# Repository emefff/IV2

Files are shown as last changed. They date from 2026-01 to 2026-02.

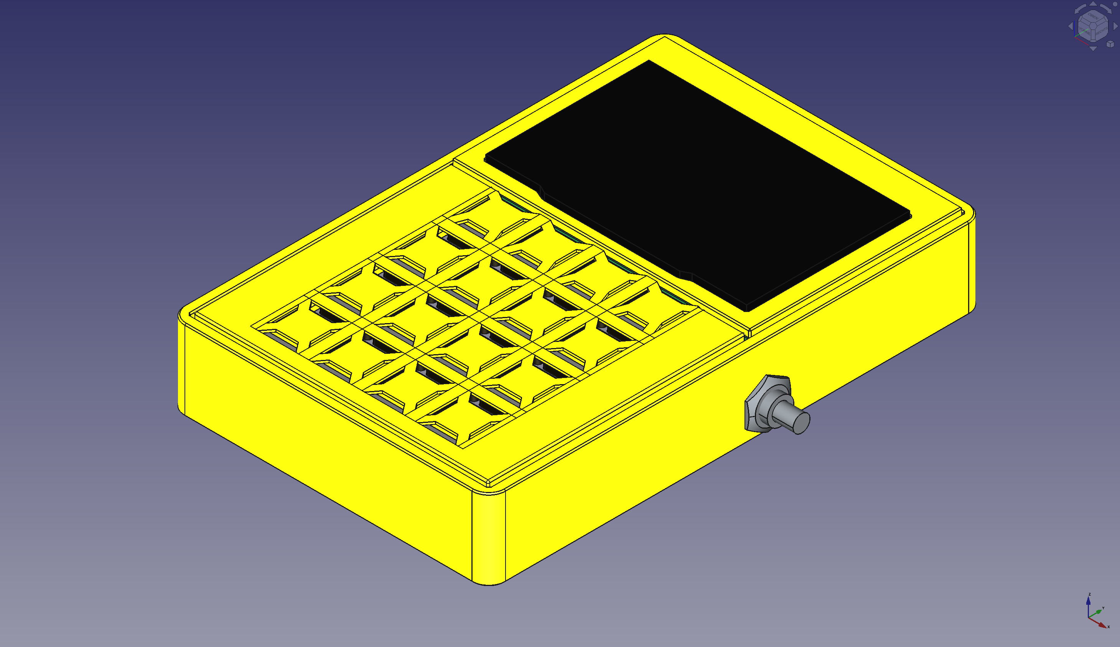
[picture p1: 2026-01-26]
hardware/CAD_overview.png

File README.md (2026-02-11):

# IVEE2 - a Powerful Programmable RPN Calculator based on IVEE

Version 1.0, (c) 2026 by emefff based on the code by deetee/zooxo.
This software is covered by the 3-clause BSD license.

## Purpose
IVEE2 is a port of IVEE to nice!nanov2. It includes some changes that make use of the faster MCU, more RAM and flash space. The main driver behind this was the limited space left on the original IVEE on ProMicro. As far as I remember only one single byte was free on the original calculator. The original code of IVEE can be found in

https://github.com/zooxo/iv

Much of it still present in IVEE2, I am publishing this with kind permission of the original developer, whom I hereby want to thank for his great work. I built his calculator many years ago, mostly by hand without any usage of CAD apart from the housing, which turned out to be rather big and clumsy. Being a fan of RPN calculators and especially the HP lineup, it gives me great pleasure to having bit this bullet and come up with this and being able to present a codebase, that has, in my opinion, great possiblities for the future on this chip. 
Nice!nanov2 is probably best known in the DIY keyboard builder community, where it is used for programmable keyboards and the like. It also has BLE capbility and uses very low power, has an onboard LiIon charging controller and USB-C connectivity. Thus, I can even imagine OTA capability for flashing and in operation for this device. Apart from that, I think of it as a worthy replacement for ESP32 in a lot of scenarios, especially for devices on battery power. 
Being an amateur programming and software enthusiast I used Kilo Code with mostly Codex-5.1, MiniMax-M2.1 and Claude Sonnet 4.5 for developing IVEE2. From this rather overwhelming experience I must say, I do not see a bright future for programmers. The evolution of the codebase was rapid, it took me about 2.5 weeks in Dec. 2025 with just 2-3 hours per day (more on weekends though). The debugging features are, from the viewpoint of an amateur C++ programmer, vastly superior than I imagined. On the other hand, being an amateur, I probably do not see where code has turned out laborious and perhaps inefficient. My approach to this was rather practical and user driven. Two of the used coding agents where very analytical in their approach to developing new functions or debugging. In the end, the codebase includes a great amount of diagnostic code, readily available for anyone to dive in. 

## Recommendations

From my experience, I started this project with Arduino, PlatformIO is the much better IDE in conjunction with  nice!nanov2. With Arduino I was not even able to upload anything, some knock-off boards do not even allow uploading .uf2 binaries, although they claim being able. Thus I recommend anyone building his/her own IVEE2 to use:

-) PlatformIO as IDE, my platformio.ini is included.

-) the original Nice!NanoV2. Granted, it is not cheap, but some of the knock-offs clearly do not work. 

-) also solder a reset button to the board. Sometimes it needs two resets before uploading the firmware.

-) a very common LiIon battery like the one used here, which can be found anywhere on this planet. If your battery capacity is even higher, nice!nanov2 allows to solder a resistor to change the charging current to 500mA instead of the standard 100mA 
(fine by me, increases battery life but takes longer to charge)

## Changes in IVEE2

### Overview of changes

-) enhanced floating point precision, doubles are now double precision instead of single.

-) 4 line stack display. I prefer this over the 2 line display of the original.

-) 32kB user memory for more storage in program mode and also longer programs. 

-) Gauss Kronrod integration instead of Simpson rule: Changing to this method allows for solving very difficult integrals
   numerically. The accuracy of this method can be adapted via GK_MAX_DEPTH. Currently it is set for acceptable duration.
   The implemented integration algorithm beats HP-42S, HP-15C and HP-41C (with ADVANCED or PPC module integration routines) 
   any time in both speed and accuracy.
   
-) WP34s style solver: the solver of WP34s written in assembler was ported. It is very capable and switches between different
   methods combining bisection, secant, quadratic interpolation, and Ridder's method. The original code can be found here:
   https://sourceforge.net/projects/wp34s/files/ .
   
-) 100 registers in flash ranging from 0-99, storing and recalling via usual commands STO and RCL.

-) 100 registers in RAM ranging from 0-99: storing and recalling via two new commands STR and RCR.

-) 1x1 pixel graphs for more accurate graphs in FPLOT.

-) 5 digit floating point display.

-) wear leveling of flash storage. nice!nanov2 can only delete 4kB pages. In order to be usable for years, a rotating wear-leveling is 
   applied to the whole user storage.
   
-) the new TOP (moveprgtop() in code) command moves a program to top of list in PRG mode: In order to not have to repeatedly UP 
   a program to the top of the list in PRG mode, mainly to FPLOT a function, the PRG chosen directly moves to the top of the list. 
   Sorting is done in RAM, only a single rewrite or user flash is necessary. TOP is on the 9 key (= KEY4 in code) in PRG mode.
   
-) Annunciator (_, f, g) moved to top right corner.

-) Builtin functions use RAM registers instead of flash.

-) CLK function slightly changed, enter hours, minutes, seconds consecutively on stack:
   e.g. 11 ENTER, 22 ENTER, 45 CLK
   starts the clock at 11:22:45. The clock does not use the built-in RTC of the nice!nanov2 but is drift compensated.
   
### More registers

In IVEE2, more registers are usable in flash and in RAM. Both range from 0-99 now. I mainly use RAM regs for intermediate storage of variables in functions, that have to be read and written very quickly. For the flash registers use the usual commands STO and RCL. For the new RAM registers use STR and RCR in a similar fashion. 

### Plotting functions

The new chip has vastly more RAM, so the full screen buffer for SSD1306 is not an issue. 1x1 pixel graphs look a lot finer that the previous 2x2 pixels. A comparison between IVEE and IVEE2 with ln from 0 to 2 is shown in the following image. The new printing algorithm also connects the dots with line elements:

<p align="center">
  
</p>

Notice also the size difference, IVEE has been built without CAD (only later the box was modeled 'around' what was already built). IVEE2 was modelled 95% in CAD --> nearly 40% of volume saved.

Just like with IVEE, the function to plot must be placed on top in the program list (use TOP for this in PRG mode). Just enter the limits and plot the function with "0 ENTER 2 FPLOT". 

### Integration algorithm 
Being an RPN calculator enthusiast and aware of their historic significance in science and engineering, I really wanted to include a better algorithm in IVEE2. An algorithm that can even outperform the algorithms present on some of the 'stars' in the RPN sky. There are many examples of functions that cannot be solved adequately with some of the most cherished (and expensive) RPN calculators. To readers of the HP Journal, specifically issue 8/1980, where professor William Kahan presented the capabilties and shortcomings of the integration algorithm developed for HP-34C, which is, to my knowledge, also included in HP-15C, HP-41C (Advantage Module) and HP-42s, this is not news. Personally, I tested numerous calculators and integration algorithms in user programs of the above mentioned calculators if they are able to solve the following integral numerically, among others. It can be found in HP Journal 8/1980 p. 28 (https://hparchive.com/Journals/HPJ-1980-08.pdf):

$$
\int_{-128}^{128} [u(u^2-47^2)(u^2-88^2)(u^2-117^2)]^2  du = 1.31026895247E28
$$

On first glance, this is solvable analytically, probably by a 16 year old pupil, right? But numerically, this integral is a different story. It is spiky between the roots and reaching large arguments. Any algorithm tackling this must either be able to resolve the spikes with a great number of intervals or be adaptive. To prove this integral is far from trivial numerically, the following image shows results calculated by the famous RPN calculators HP-41CX, HP-15C and HP-42S:

<p align="center">
  
</p>

HP41c uses the INTEG command from the Advantage module, the others use their onboard integration algorithm. All three calculators fail solving the integral. They are able to solve it in the halved interval from 0 to 128, though. This is also mentioned by Prof. Kahan in above article:

<p align="center">
  
</p>

The only way out with these calculators in solving such integrals is to write your own integration algorithms in user code, die-hard HP41c users might even write MCODE. 
In IVEE2, the above function can make use of RAM register nr. 1 (of course it can be done with the stack too) when entering something like the following. The squares of 47, 88 and 117 are stored in flash registers 97, 98 and 99:

"1, STR, CLR, 1, RCR, 2, POW, 99, RCL, -, 1, RCR, 2, POW, 98, RCL, -, *, 1, RCR, 2, POW, 97, RCL, -, *, 1, RCR, *, 2, POW"

To integrate this function place in on top of the PRG list and enter the limits on the stack: "128 N ENTER ENTER N FINT". 

Let's see how IVEE2 does:
<p align="center">
  
</p>

Clearly, we find the implemented algorithm can in fact solve this integral. The only downside is the number of digits displayed. Internally, looking at the serial monitor, we will find a vastly better accuracy. On stack level a we find the absolute error of the calculation, stack level b shows the result. 

### Solver/Root finder

The solver implemented is, more or less, an exact port from wp34s (written in Assembler, the source can be found here: https://sourceforge.net/projects/wp34s/files/) to C++. It is a very capable solver, combining and switching between bisection, secant, quadratic interpolation, and Ridder's method. Like with integration (FINT), the function of interesest must be placed on top of the PRG list. To find the root of a function enter a start interval (X and Y) and press FSOLVE. There are measures in place, that start the solver anyway with random values, if only one or no value is on the stack. However, in a function with multiple roots you will likely not find the desired root (or none at all!) if no interval is given. For example, with above function we get:

"40 ENTER 80 FSOLVE" --> "7.17527E-13"

"50 FSOLVE" --> "47"

"90 FSOLVE" --> "88"

"118 FSOLVE" --> "117"

Clearly, the better you already know your function, the more likely you will find all roots. 

## Programming

Programming is basically unchanged from IVEE but with a lot more storage in flash, so I will just give a brief description. If you are familiar with programming the HP-41C or HP42S, then you will not have any difficulties. Programs are entered RPN style, like on HP-41C, but we can also use the menu like on HP-42s (similar but a bit different. We can choose functions from the DICT or USER menu). The main difference to the RPN style on HP-41c is that we don't need RTN or VIEW to present a value on the stack, we also don't have the function LBL within the function itself. The name of the function is outside the function/program. Already included complex number capabilites for every function are an improvement over HP-41C, but displaying is not as convenient as on HP-42s (HP-42s: single line complex numbers, but reduced number of digits, IVEE2: two line display of complex numbers). For example, the program "0, SWP, CPX, EXP" returns EXP(i*x). And indeed, "PI F(X)" gives "a -1, i -8.74228E-8", the complex identity 

$$
\exp(i*\pi) = -1
$$

with a bit of a rounding error in the imaginary part, though. 

Now, let us test a version of the TVM formula with monthly payments (we use the notation on the HP-12c):

$$
FV(n) = PV * (1+i)^n + PMT * [(1+i)^n − 1)/i]
$$

i...yearly interest rate

n...months

FV...future value

PMT...monthly payment

PV...present value

Entering this on IVEE2 we have different options. Making use of flash and RAM registers we may enter a formula in PRG mode like this:

"0, STR, CLR, 0, RCL, 1, +, 0, RCR, POW, 1, RCL, *, 0, RCL, 1, +, 0, RCR, POW, 1, -, 0, RCL, /, 2, RCL, *, +, 3, RCL, -"

First we store n in RAM reg nr. 0, we CLR the stack, then enter the formula. When we put it on top in PRG mode, we can use FSOLV (fS internally) to solve for n at FV = 0, that is, we want to find the number of months we have to pay back the 100 bucks. For our example we use the follwing numbers in 4 flash registers 0-3:

i = 0.08 ("0.08 ENTER 0 STO")

PV = 1000 ("1000 ENTER 1 STO")

PMT = -100 ("100 N ENTER 2 STO")

FV = 0 ("0 ENTER 3 STO")

Just pressing FSOLV will yield: 20.921237. Comparing with HP-12c (i=8, PV=1000, PMT=-100, FV=0) pressing the n-button:

<p align="center">
  
</p>

The results match as HP-12c rounds up to the next integer. From this funny little example we have learned that an interest rate of 8% is quite high and we have to pay more than double the amount back. Horrible!

## Hardware

Of couse, a one-off model like this calculator is destined for 3D printing. In the shared folder 'hardware' you'll find a FreeCAD file with the latest design. Everything is modeled in CAD. This can be quite deceiving: thinking you have modeled 'everything', you forget about stupid mistakes to be made with stuff you didn't model. This happened here with the wiring. Any sane person would not model this in 3D, the designing of every wire alone would take too long, with limited benefit. But here it would have helped: the distance between MCU board and battery is crucial for the position of the USB-C cutout in the housing! Forgetting about this or not leaving enough room for wires that bend and need space, has left me with a MCU board position, that did not quite fit the modeled USB-cutout. A very basic and stupid mistake. :-(

Overview of the CAD:
<p align="center">
  
</p>

View of the parts inside:

<p align="center">
  
</p>

The 3D printed parts are all PETG except the display frame which was made in PLA. The parts are:

-) housing

-) display frame

-) MCU board adapter (includes a tiny socket for a reset button)

-) keyboard matrix (a thin matrix covering the buttons and leaving a flat surface for a thin printed keyboard overlay)

The layout of the calculator is based around a perforated circuit board with standoffs to the bottom for making the necessary space for wiring, battery and MCU board. The MCU board is mounted onto an adapter which is in turn mounted to the circuit board. Everything is made to last and to be replaceable. The keys are quite generic, as is the SSD1306 display. The whole assembly is held in the housing with 6 magnets glued into the housing. The battery is glued in place, as is the display. Screw heads are covered with the display frame and the keyboard matrix, respectively. The inner workings of my build look like this:

<p align="center">
  
</p>

Try to keep it nice and tidy, a long battery cable pays off in the end and during the build. 
The keyboard matrix shown in these pictures is still the old version. 

Recommendations for 3D printing:
If you can, use at least PETG on a TXT sheet (not as brittle as PLA, a PLA housing can break when falling off a table). Print a 5mm brim or mouse ears at the corners of the housing as it is quite large. Also use a brim on the keyboard matrix, the adapter is quite small, maybe a smaller brim will do also. The display frame in PLA does not need a brim, it sticks very well to a PEI sheet. Use structural mode and 3 perimeters for the housing and two perimeters for the keyboard matrix (both see some mechanical loads), maybe even 0.15mm layers. The keyboard matrix must stay somewhat flexible for a lower button force. There are even variants of the housing in the FreeCAD file that include a brim in CAD. Feel free to use this or add a brim in your slicer. 

### Additional Parts needed

-) Cables

-) wires

-) 6x standoff nuts for short M3 * 5mm screws

-) 6x 4 * 4 *2mm magnets

-) 6x M3 * 5mm screws

-) 1x perforated PCB, prefer the ones with lugged holes, not the ones with just holes. The lugs make soldering something to the holes easier

-) double-sided tape, also to correct height differences

-) hot glue

-) Kapton tape for isolation where needed

-) 2x resistor for the voltage divider, here 2x 10k (not good regarding voltage resulotion but ok)

-) 1x On/Off switch

-) USB-C cable for flashing and charging the LiIon battery

-) 1x 4 * 4mm reset button, fits the twerp on the adapter for the MU

-) optional phone charger 

# ToDos

-) new keyboard overlay to be designed fitting this keyboard layout. The layout shown in the images is still the old design. I will upload the files when this is completed.

-) anything important that comes up, we'll see.

maybes:

-) perhaps move the annunciator back to the old position for base modes other than scientific.

-) the statistical functions were not tested, because I do not need them. With the increased flash registers there are much more possibilities.

-) perhaps use the onboard RTC for the clock and maybe implement a stopwatch, date and time functions. Maybe similar to TIME module on HP41c. 

Have fun,

emefff@gmx.at

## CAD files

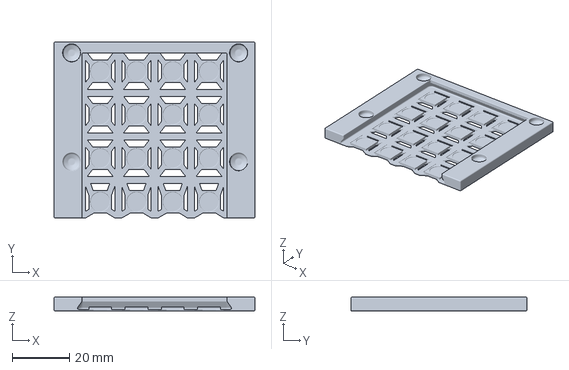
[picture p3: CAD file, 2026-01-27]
hardware/IVEE2_Model_V7-Keyboardmatrix.3mf
70.3 x 61.5 x 4.80 mm

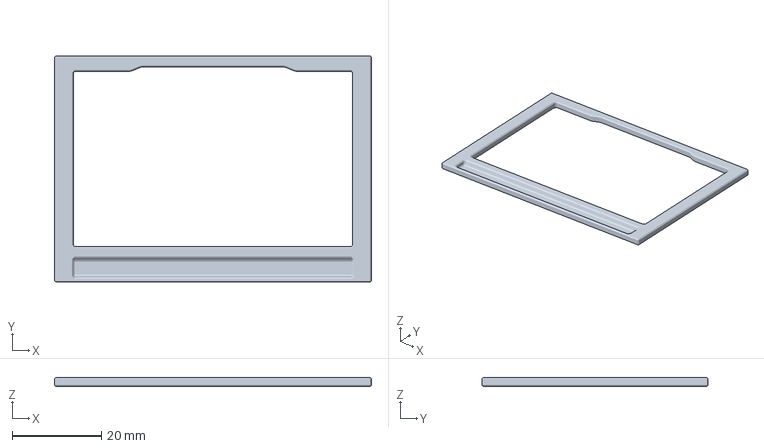
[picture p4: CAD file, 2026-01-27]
hardware/IVEE2_Model_V5-frame_display.3mf
71.1 x 50.8 x 2.00 mm

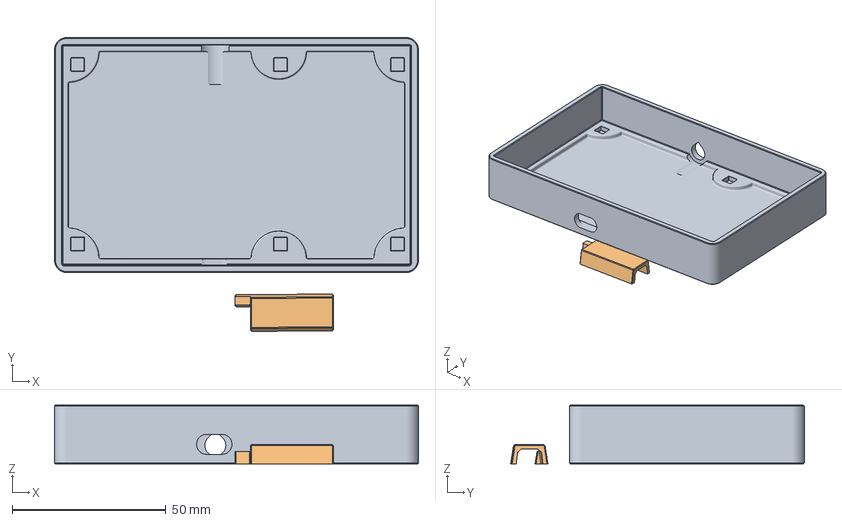
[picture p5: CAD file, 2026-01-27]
hardware/IVEE2_Model_V4-Box_wCutouts_higher+0.5.3mf
118.5 x 95.7 x 19.2 mm
IVEE_V2_Model_V4_Gehaeuse_hoeher-BOX_wCutouts_sideWalls_higher+0
IVEE_V2_Model_V4_Gehaeuse_hoeher-ADAPTER_new_eumelLonger+1mm

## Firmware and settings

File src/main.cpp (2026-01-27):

/*

  ____________________

  Welcome to IVEE2 - A Powerful Programmable and Expandable RPN Calculator based on IVEE
  Version 1.0, (c) 2026 by emefff based on the code by deetee/zooxo. 
  This software is covered by the 3-clause BSD license.
  See also: https://github.com/emefff/ivee2 
  ____________________


IVEE2 is a port of IVEE to nice!nanoV2. All credit for the orginal design goes to detee, his code for Arduino 
ProMicro is the basis for this calculator. You can find the original code in

https://github.com/zooxo/iv

With his kind permission, I can publish the ported code. Basic functions of the calculator are 
the same, with some enhancements of built-in code and the benefits that come with a more capable chip. 

The main purpose of this port is to have a simple calculator like IVEE and at the same time have a calculator
that still can evolve. This was not possible on ProMicro because there was only a single byte left in flash. 
I strongly encourage everyone to add functions (both in code and FORTH) and to learn about
how a calculator works. Maybe there's also an educational purpose/value in this for EE or SE students.

Kilo Code was used in developing this calculator, models used were mostly Codex-5.1, MiniMax M2.1 and Claude Sonnet 4.5.
The calculator features a lot of diagnostics over serial and was quite extensively tested. The main development took 
about 2.5 weeks in Dec. 2025 with 2-3 hours per day, more on weekends. The author is not a professional programmer or software
engineer, rather an advanced amateur software and calculator enthusiast. 

Changes and enhancements include:

-) enhanced floating point precision, doubles are now double precision instead of single.
-) 4 line stack display. I prefer this over the 2 line display of the original.
-) 32kB user memory for more storage in program mode and also longer programs. 
-) Gauss Kronrod integration instead of Simpson rule: Changing to this method allows for solving very difficult integrals
   numerically. The accuracy of this method can be adapted via GK_MAX_DEPTH. Currently it is set for acceptable duration.
   The implemented integration algorithm beats HP42, HP15C and HP41c (with ADVANCED or PPC module integration routines) 
   any time in both speed and accuracy.
-) WP34s style solver: the solver of WP34s written in assembler was ported. It is very capable and switches between different
   methods combining bisection, secant, quadratic interpolation, and Ridder's method. The original code can be found here:
   https://sourceforge.net/projects/wp34s/files/ .
-) 100 registers in flash ranging from 0-99, storing and recalling via usual commands STO and RCL.
-) 100 registers in RAM ranging from 0-99: storing and recalling via two new commands STR and RCR.
-) 1x1 pixel graphs for more accurate graphs in FPLOT.
-) 5 digit floating point display.
-) wear leveling of flash storage. nice!nanov2 can only delete 4kB pages. In order to be usable for years, a rotating wear-leveling is 
   applied to the whole user storage.
-) the new TOP (moveprgtop() in code) command moves a program to top of list in PRG mode: In order to not have to repeatedly UP 
   a program to the top of the list in PRG mode, mainly to FPLOT a function, the PRG chosen directly moves to the top of the list. 
   Sorting is done in RAM, only a single rewrite or user flash is necessary. TOP is on the 9 key (= KEY4 in code) in PRG mode.
-) Annunciator (_, f, g) moved to top right corner.
-) Builtin functions use RAM registers instead of flash.
-) CLK function slightly changed, enter hours, minutes, seconds consecutively on stack:
   e.g. 11 ENTER, 22 ENTER, 45 CLK
   starts the clock at 11:22:45. The clock does not use the built-in RTC of the nice!nanov2 but is drift compensated

   
This concludes the most important changes exposed to the user.

The following part of this docstring is mostly copied from https://github.com/zooxo/iv and adapted to IVEE2 to explain the basic original
and the new functions:

Ivee2 is operated by 16 keys only it offers a wide range of functions
  and possibilities:
  - 122 intrinsic functions based on FORTH
  - increased user space (32kB)
  - Programming: Handle up to 40 user definable programs with max. 256 steps
                 (Edit, New, Rename, Move, Delete, Send, Load)
  - Dictionary of all commands (sorted), words and programs
  - Fast user definable menu (longpressed F-key)
  - Calculations with complex numbers for nearly every function
  - Calculus (f(x), plot, solve, integrate)
  - Basic math operations in number systems with selectable BASE
  - Business calculator mode (accuracy of 18 digits)
  - Save up to 100 numbers/constants permanently
  - Save up to 100 numbers in RAM
  - Statistics and line best fit (not tested yet)
  - Many unit conversions
  - Clock and Torch function
  - Basic system functions (Battery voltage, Brightness (does not work with my SSD1306, though), Screensaver)
  - due to massive RAM and flash compared to ProMicro, IVEE2 is expandable in many ways.


  ____________________

   KEYBOARD, SHORTCUTS
  ____________________

    F(G)[OFF]{MENU}  7(S+)[SCLR]    8(PRG)[BASE]    9(/)[MOD]
    E(SWAP)[ROT]     4(DICT)[USR]   5(FX)[FPLOT]    6(*)[LIT]
    N(OVER)[PICK]    1(RCL)[STO]    2(SOLVE)[FINT]  3(-)[LIT-]
    X(CLR)[TOFF]     0(CPLX)[BATT]  .(R<>P)[CLK]    #(+)[LIT+]

    PRG Shortcuts:                  BASE/HEX Shortcuts:
                    9 TOP            
             5 OUT  6 UP              4 E  5 F
      1 NEW  2 IN   3 DOWN            1 B  2 C    3 D
      0 REN  . DEL  D EDIT            0 A  . A~F

    MENU/DICT/REN Navigation:       SUM/STAT/L.R. Storage Registers:
             Q1  Q2  Q3  Q4           7 SN  8 SX   9 SY
      UP     E   4   5   6                  5 SXX  6 SXY
      DOWN   N   1   2   3
             PREV0   .NEXT


  ____________________

   DISPLAY, INDICATORS
  ____________________

    >        ... Empty stack, ready to calculate
    >        ... Indicates selected program in program selection mode
    <        ... Indicates selected program step in program editing mode
    a~z      ... Stack level
    _        ... Indicates number input
    i, angle ... Imaginary part, imaginary angle
    B        ... BASE mode indicator
    n BASE   ... Numeric base of BASE mode
    !        ... Indicates float of data stack (data loss in lowest stack level)
    ^, v     ... F-key, G-key
                
                
  ____________________

   LIMITS
  ____________________

    26   ... Maximum data stack size (a...z)
    7    ... Maximum number of displayed significant digits of a number
    99   ... Maximum number of decimal exponent digits (1E-99 < X < 1E99)
    12   ... Maximum size of text display (see EMIT, CTX)
    100  ... Maximum amount of (complex) numbers saved permanently (0...99)
    100  ... Maximum amount of (complex) numbers saved in RAM      (0...99)
    3    ... Maximum number of characters for naming an user program
    40   ... Maximum number of user programs
    256  ... Maximum size of an user program (steps)
    ~32000  ... Maximum size (steps) of all user programs
    64   ... Maximum size of address stack ("deep of nesting")
    32   ... Maximal definable command slots of user menu                
                

  ____________________

   BROWSING MENUS
  ____________________

    To navigate through the menu of some functions (MENU, DICT, USR, renamePRG)
    all selectable items are divided into four sections. Every section has its
    own up and down key (section I: E/N, section II: 4/1, section III: 5/2 and
    section IV: 6/3).
    To move to the previous or next entry (regardless which section is selected)
    the keys "0" or "." can be used. To select one of the four presented items
    use the appropriate function key (F/7/8/9) or escape the menu with "X".


  ____________________

   PROGRAMMING
  ____________________

    Ivee2 is able to deal with up to 40 user programs with a total number of
    ~32000 steps/commands. To handle/edit/create user programs enter the program selector mode
    with PRG.
    While in the program selection mode on the left side of the display the
    available programs are numbered and listed. On the right side of the display
    the number of programs, the memory used and the memory available are shown.
    To navigate between programs use the cursor keys E (up) and N (down).
    Edit a selected program with # or press 1 to enter a new program.
    To delete a program press "." - to rename it use the key 0.
    You can move a program with 6 up or with 3 down. A program can be moved to the 
    top of the list with TOP pressing 9. Note that the top program
    has special calculus features (f(x), plot, solve, integrate).
    To send a program (does not include the program name) via USB to another
    computer press "5". Note that corresponding ascii characters will be sent
    (see chapter DICTIONARY, second column). In a similar way programs can be
    send from another computer to Ivee (press key 2) and will be stored as new
    program.
    With the 3 powerful commands @, ! and EXE (see chapter DICTIONARY) it is
    even possible to manipulate the program memory and execute code.
    A program is structured into the three parts NAME, COMMANDS and EOP-marker.
    Please note that the length of the program name is restricted to 3
    characters and the maximum number of program steps is restricted to 256.
    
    
  ____________________

   BASE, BUSINESS MODE
  ____________________

    To calculate with integer values in other numeric base enter the base and
    select the BASE command (ie 16 BASE to calculate with hexadecimal numbers).
    To return to the scientific mode press BASE again. When changing the mode
    the whole stack will be converted (as far as appropriate) to the new base.
    Numbers will be displayed in groups of four digits in two lines with a
    B-indicator (BASE) on the left side and the base itself on the right side of
    the first line. Pressing "E" enters four zeros.
    Note that only basic operations (/*-+) and some stack operations are
    supported. To enter digits bigger than 9 (ie F) press "." followed by a key
    (ie 5 to enter F).
    The BASE can be stored permanently. However, currently it is set to start in 
    scientific mode, always.
    Entering the BASE mode with 10 activates the business mode to deal with big
    numbers and high accuracy, like trillions of dollars with cent accuracy.
    Numbers are grouped into triples and two digits after the decimal dot
    (cents) are supported.


  ____________________

   CALCULUS
  ____________________

    Ivee2 is able to analyze the first user defined program. Note that you can
    move the desired user program to the first position with the TOP command pressing
    9 directly or using the keys 6 or 3 in program mode (PRG).
    To calculate the value of a function use F(X).
    To find the root of a function enter a start interval (X and Y) and press FSOLVE. 
    There are measures in place that start the solver anyway with random values, if no
    value is on the stack or only one value. However, in a function with multiple roots
    you will likely not find the desired root (or none at all!) if no interval is given.
    Enter the x-range (from Y to X) before plotting a function (FPLOT) or
    calculating an integral (FINT).


  ____________________

   COMMANDS
  ____________________

  MEMORY
       functions         mem[]       EEPROM
    |<--intrinsic-->|<--builtin-->|<--user-->|
     0               76            121        164
              MAXCMDI^      MAXCMDB^   MAXCMDU^


  OVERVIEW
    Intrinsic
      Forth  DUP DROP NEGATE / * - + MOD DICT SWAP ROT PICK
             < = <> > KEY EMIT BASE BEGIN UNTIL IF ELSE THEN @ !
      System 0~9 . E STO RCL CLR USR NAND INTEGER PI INV SIN EXP LN
             COMPLEX REC<>POL F(X) FPLOT FSOLVE FINTEGRATE
             PRG T+ PSE EXE BREAK CLRTEXT ISREAL
             SUM+ SUM- SUMCLR COMB PERM STAT LR
             BATT LIT LIT+ LIT- CLOCK OFF TOFF STR RCR
    Builtin
      Forth  OVER HEX AND NOT OR ABS
      Other  $ SQRT POWER POWER10 LOG LN! PV ND QE HMS>H H>HMS CLOCK
             COS TAN ASIN ACOS ATAN SINH COSH TANH ASINH ACOSH ATANH
             DEG>RAD RAD>DEG C>F F>C KM>MI MI>KM M>FT FT>M CM>IN IN>CM
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
void loop() {
  //Serial.print("MAGIC: "); Serial.println(digitalRead(MAGICKEYPIN));

#if ENABLE_WRITE_COUNTERS
  // Handle diagnostic commands via Serial
  if (Serial.available() > 0) {
    char cmd = Serial.read();
    if (cmd == 'S' || cmd == 's') {
      EEPROM.printWriteStats();
    } else if (cmd == 'R' || cmd == 'r') {
      EEPROM.resetWriteStats();
    } else if (cmd == 'B' || cmd == 'b') {
      // Brightness wear-leveling test
      Serial.println(F("\n[TEST] Running brightness wear-leveling test..."));
      Serial.println(F("[TEST] Writing 20 brightness values"));
      for (int i = 0; i < 20; i++) {
        EEPROM.putBrightness(100 + i);
        Serial.print('.');
        delay(10);
      }
      Serial.println(F("\n[TEST] Complete. Send 'S' to see distribution."));
    } else if (cmd == 'D' || cmd == 'd') {
      // Darktime wear-leveling test
      Serial.println(F("\n[TEST] Running darktime wear-leveling test..."));
      Serial.println(F("[TEST] Writing 12 darktime values"));
      for (int i = 0; i < 12; i++) {
        EEPROM.putDarktime(6 + i);
        Serial.print('.');
        delay(10);
      }
      Serial.println(F("\n[TEST] Complete. Send 'S' to see distribution."));
    }
  }
#endif

  if (isprintscreen) isprintscreen = printscreen(); // Print screen
  if (pause) { // Pause
    delaylong(pause);
    pause = 0;
  }

  if (mp) { // *** Execute/run code
    if (mp < sizeof(mem)) key = mem[mp++]; // Builtin
    else if (mp < sizeof(mem) + sou){
      byte tmp;
      EEPROM.get(mp - sizeof(mem) + EEUSTART, tmp); // read from EEPROM
      key = tmp;                                    // assign to key
      mp++;                                         // post-increment
    }
    else mp = 0; // cmd > MAXCMDU
    
    // log program execution steps
    #if LOG_PRG_MEMPTR
    if (Serial && key != 255) {
      Serial.print("[PRG] mp="); Serial.print(mp);
      Serial.print(" key="); Serial.print(key);
      Serial.print(" dp="); Serial.println(dp);
      Serial.flush(); // Force output
    }
    #endif
    
#if LOG_FX_FI_STACK
    if (Serial && key != _END && key < NOPRINTNOKEY) {
      Serial.print("[EXEC_STEP] cmd="); Serial.print(key);
      if (key < MAXCMDB && key < sizeof(cmd)/sizeof(cmd[0])) {
        Serial.print(" name="); Serial.print(cmd[key]);
      }
      Serial.print(" BEFORE - dp="); Serial.print(dp);
      Serial.print(" ap="); Serial.print(ap);
      Serial.print(" STACK: ");
      for (byte i = 0; i < dp && i < 6; i++) {
        Serial.print(ds[i].r, 3); Serial.print(" ");
      }
      Serial.println();
      Serial.flush();
    }
#endif
    
    if (key >= MAXCMDB && key != _END) apush(mp); // Subroutine detected - branch (only user programs, not builtin RAM commands)
    if (key == _END) { // _END reached
#if LOG_FX_FI_STACK
      if (Serial) {
        Serial.print("[EXEC_END] ap="); Serial.print(ap);
        Serial.print(" dp="); Serial.print(dp);
        Serial.print(" STACK: ");
        for (byte i = 0; i < dp && i < 6; i++) {
          Serial.print(ds[i].r, 3); Serial.print(" ");
        }
        Serial.println();
      }
#endif
      if (ap) mp = apop(); // End of subroutine - return
      else { // End of run
        mp = 0;
        isprintscreen = true; // Finally print screen
        #if LOG_PRG_MEMPTR
          if (Serial) Serial.println("[PRG] Program END - execution complete");
        #endif
      }
    }
    else {
#if LOG_RAM_STORCL
      if (Serial && (key == _STO_RAM || key == _RCL_RAM)) {
        Serial.print("[LOOP] About to execute cmd=");
        Serial.print(key == _STO_RAM ? "STO_RAM" : "RCL_RAM");
        Serial.print(" dp="); Serial.print(dp);
        Serial.print(" isnewnumber="); Serial.println(isnewnumber);
      }
#endif
#if LOG_PRG_MEMPTR
      if (Serial && key == _RCL) {
        Serial.println("[PRG] *** ABOUT TO EXECUTE RCL ***");
      }
#endif
      execute(key);
#if LOG_FX_FI_STACK
      if (Serial && key < NOPRINTNOKEY) {
        Serial.print("[EXEC_STEP] AFTER - dp="); Serial.print(dp);
        Serial.print(" ap="); Serial.print(ap);
        Serial.print(" STACK: ");
        for (byte i = 0; i < dp && i < 6; i++) {
          Serial.print(ds[i].r, 3); Serial.print(" ");
        }
        Serial.println();
        Serial.flush();
      }
#endif
#if LOG_PRG_MEMPTR
      if (Serial && key == _RCL) {
        Serial.println("[PRG] *** RCL EXECUTE DONE ***");
      }
#endif
#if LOG_RAM_STORCL
      if (Serial && (key == _STO_RAM || key == _RCL_RAM)) {
        Serial.print("[LOOP] After execute dp="); Serial.print(dp);
        Serial.print(" isnewnumber="); Serial.println(isnewnumber);
      }
#endif
    }
    digitalWrite(KEYBOARDCOL1, LOW); // Stop by pressing C
    if (!digitalRead(KEYBOARDROW4)) mp = ap = 0;
    digitalWrite(KEYBOARDCOL1, HIGH);
  }

  else { // *** Evaluate valid new key
    if (!(nextFrame())) return; // Idle for next frame
    key = getkey(); // READ KEY
    if (key < NOPRINTNOKEY) { // only if valid key otherwise flooding with NOPRINTNOKEY
      Serial.print("Key read: ");
      Serial.println(key);
      // Debug matrix pins
      Serial.print("COL1: "); Serial.print(digitalRead(KEYBOARDCOL1));
      Serial.print(" ROW4: "); Serial.println(digitalRead(KEYBOARDROW4));
    }

    if (key == KEY13) { // Stop execution
      issolve = isint =  isplot = istorch = false;
      gkResetController();
      clockState.active = false; // Stop clock
      powertimestamp = millis(); // Reset power management timer
    }
    if (key == KEY1 && !base) { // Check MENU (longpressed f)
      if (millis() - timestamp > FLONGPRESSTIME) {
        if (isprgedit) { // Menu from prgedit demanded
          isprgmenu = true; isprgedit = false;
        }
        else { // Menu demanded
          fgm = 0;
          freleased = false;
        }
        ismenu = isprintscreen = true;
        sel = 0; // Comment out, if menu should't start at 0
      }
    }
    else timestamp = millis();

    if (millis() - powertimestamp > darktime * 10000L) { // Dark if no activity
      // Don't sleep if clock is active - keep device running to maintain clock accuracy
      if (!clockState.active) {
        Serial.print("[POWER] Screen timeout after ");
        Serial.print((millis() - powertimestamp) / 1000);
        Serial.print("s (darktime=");
        Serial.print(darktime);
        Serial.print(" = ");
        Serial.print(darktime * 10);
        Serial.println("s)");
        _keygoff();
        isprintscreen = true;
      }
      // Update powertimestamp to prevent repeated checking when clock is active
      powertimestamp = millis();
    }

    if (issolve) { // # SOLVE
      cycles++;

      dp = 0; // Clear stack for new solve

#if LOG_SOLVE
      Serial.print("[SOLVE] before _fnfx mp=");
      Serial.println(mp);
#endif
      bool endpointsReady = evaluateFxImmediate(x0, w0);
      if (endpointsReady) endpointsReady = evaluateFxImmediate(x1, w1);

      if (!endpointsReady) {
        issolve = false;
        msgnr = MSGRUN;
        isprintscreen = true;
      }
      else {
#if LOG_SOLVE
        if (Serial) {
          Serial.print("[SOLVE] y0="); Serial.print(w0);
          Serial.print(" y1="); Serial.println(w1);
        }
#endif

        double root = hybridSolve(x0, x1, w0, w1, 1e-12, 250); //wp34s style solver
        dpushr(root); // Push root found

        if (Serial) { // always serial.print the root.
          Serial.print("\n[SOLVE] Root="); Serial.println(root);
        }
        isnewnumber = true; issolve = false;
        isprintscreen = true;
      }
    }
    else if (isint) { // # INTEGRATE - Adaptive Gauss-Kronrod
      if (!gkController.active) {
        isint = false;
      }
      else {
        cycles++;
#if LOG_FX_FI_STACK
        if (Serial) {
          Serial.print("[FI] BEFORE execute - eval#"); Serial.print(gkEvalCount + 1);
          Serial.print(" node="); Serial.print((int)gkController.nodeIndex);
          Serial.print(" x="); Serial.print(gkCurrentNodePosition(), 8);
          Serial.print(" dp="); Serial.print(dp);
          Serial.print(" ap="); Serial.print(ap);
          Serial.print(" STACK: ");
          for (byte i = 0; i < dp && i < 8; i++) {
            Serial.print("["); Serial.print(i); Serial.print("]=");
            Serial.print(ds[i].r, 6);
            if (ds[i].i != 0.0) {
              Serial.print("+j"); Serial.print(ds[i].i, 6);
            }
            Serial.print(" ");
          }
          Serial.println();
        }
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

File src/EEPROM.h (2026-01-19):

#include <Arduino.h>
#include <stdint.h>
#include <cstring>

//#define FLASH_PAGE_SIZE 0x2000  // 8 KB page, was 4kB 0x1000 before
#define FLASH_PAGE_SIZE 0x8000    // 32 KB page, was 8kB 0x1000 before, notably sluggish with 64kB

#define EEPROM_PAGE_POOL 8                 // Number of rotating 32 KB pages
#define EEPROM_PAGE_HEADER_SIZE 32         // Bytes reserved at top of each page for metadata
static_assert(EEPROM_PAGE_HEADER_SIZE < FLASH_PAGE_SIZE, "EEPROM header must fit inside a page");

constexpr uint32_t kEepromPageMagic = 0x4550524DL; // 'EPRM'
constexpr bool kEnableEepromWrites = true;         // #define DONT_CLEAR_USER_FUNCTIONS on first flashing.

// Wear-leveling diagnostics
#define ENABLE_WRITE_COUNTERS 0  // comment to disable for production
#if ENABLE_WRITE_COUNTERS
#define WRITE_COUNTER_SIZE 256   // Track first 256 logical addresses
static uint32_t writeCounters[WRITE_COUNTER_SIZE] = {0};
#endif

// Wear-leveling for frequently written single-byte values
#define WL_BRIGHTNESS_SLOTS 8    // Rotate brightness across 8 addresses
#define WL_BRIGHTNESS_START 2048 // 256b with MEMNR=10, 2048b with MEMNR=100
#define WL_BRIGHTNESS_INDEX (WL_BRIGHTNESS_START + WL_BRIGHTNESS_SLOTS)
#define WL_DARKTIME_SLOTS 4
#define WL_DARKTIME_START 272
#define WL_DARKTIME_INDEX (WL_DARKTIME_START + WL_DARKTIME_SLOTS)

static inline uint32_t bootloaderStartAddr() {
    constexpr uint32_t BOOTLOADERADDR_REG = 0x10001014UL;
    return *((volatile uint32_t*)BOOTLOADERADDR_REG);
}

static inline uint32_t eepromFlashBase() {
    uint32_t pageSize = NRF_FICR->CODEPAGESIZE;
    uint32_t totalSize = pageSize * NRF_FICR->CODESIZE;
    uint32_t bootAddr = bootloaderStartAddr();
    if (bootAddr == 0xFFFFFFFF) bootAddr = totalSize;
    uint32_t poolSize = FLASH_PAGE_SIZE * EEPROM_PAGE_POOL;
    if (bootAddr < poolSize) bootAddr = poolSize;
    return bootAddr - poolSize; // Lowest address of the rotating pool
}

class EEPROMEmu {
public:
    EEPROMEmu();

#if ENABLE_WRITE_COUNTERS
    void printWriteStats();
    void resetWriteStats();
#endif

    template <typename T>
    void put(int offset, const T& value) {
        ensureInitialized();
        const uint8_t* src = reinterpret_cast<const uint8_t*>(&value);
        size_t len = sizeof(T);
        uint32_t targetAddr = physicalDataAddress(offset);

#if ENABLE_WRITE_COUNTERS
        for (size_t i = 0; i < len && (offset + i) < WRITE_COUNTER_SIZE; ++i) {
            writeCounters[offset + i]++;
        }
#endif

        programBytes(targetAddr, src, len);
    }

    template <typename T>
    void get(int offset, T& value) {
        ensureInitialized();
        const uint8_t* src = reinterpret_cast<const uint8_t*>(physicalDataAddress(offset));
        std::memcpy(&value, src, sizeof(T));
    }

    int length() {
        return FLASH_PAGE_SIZE - EEPROM_PAGE_HEADER_SIZE;
    }

    uint8_t operator[](int address) {
        uint8_t val;
        get(address, val);
        return val;
    }

    void set(int address, uint8_t val) {
        put(address, val);
    }

    bool beginPageRewrite();
    uint32_t activePageBase() const { return pageBase(activePage); }

    // ----- wear-level helpers for small single-byte slots -----
    uint8_t findNextSlot(uint8_t baseAddr, uint8_t numSlots);
    uint8_t findCurrentSlot(uint8_t baseAddr, uint8_t numSlots);
    void putBrightness(uint8_t brightness);
    uint8_t getBrightness();
    void putDarktime(uint8_t darktime);
    uint8_t getDarktime();

private:
    struct PageHeader {
        uint32_t magic;
        uint32_t generation;
        uint32_t generationInverse;
        uint32_t reserved;
    };

    void ensureInitialized();
    void initPool();
    uint32_t poolBase() const { return poolBaseAddr; }
    uint32_t pageBase(uint8_t idx) const { return poolBaseAddr + static_cast<uint32_t>(idx) * FLASH_PAGE_SIZE; }
    uint32_t dataBase(uint8_t idx) const { return pageBase(idx) + EEPROM_PAGE_HEADER_SIZE; }
    uint32_t physicalDataAddress(int offset) const { return dataBase(activePage) + static_cast<uint32_t>(offset); }
    void programBytes(uint32_t targetAddr, const uint8_t* src, size_t len);
    void eraseLogicalPage(uint8_t pageIdx);
    bool readHeader(uint8_t pageIdx, PageHeader& out) const;
    void writeHeader(uint8_t pageIdx, uint32_t generation);
    bool rotateToNextPage();
    uint8_t nextPageIndex(uint8_t idx) const { return (idx + 1) % EEPROM_PAGE_POOL; }

    uint32_t poolBaseAddr;
    uint8_t activePage;
    uint32_t activeGeneration;
    bool initialized;
};

inline EEPROMEmu::EEPROMEmu()
    : poolBaseAddr(0), activePage(0), activeGeneration(0), initialized(false) {}

#if ENABLE_WRITE_COUNTERS
inline void EEPROMEmu::printWriteStats() {
    if (!Serial) return;
    Serial.println(F("\n=== EEPROM WRITE STATISTICS ==="));
    uint32_t total = 0;
    for (int i = 0; i < WRITE_COUNTER_SIZE; ++i) {
        if (writeCounters[i] > 0) {
            Serial.print(F("Addr 0x"));
            if (i < 16) Serial.print('0');
            Serial.print(i, HEX);
            Serial.print(F(": "));
            Serial.println(writeCounters[i]);
            total += writeCounters[i];
        }
    }
    Serial.print(F("Total byte writes: "));
    Serial.println(total);
    Serial.println(F("==============================\n"));
}

inline void EEPROMEmu::resetWriteStats() {
    memset(writeCounters, 0, sizeof(writeCounters));
    if (Serial) Serial.println(F("[EEPROM] Write counters reset"));
}
#endif

inline void EEPROMEmu::ensureInitialized() {
    if (!initialized) initPool();
}

inline void EEPROMEmu::initPool() {
    poolBaseAddr = eepromFlashBase();
    PageHeader hdr{};
    bool found = false;
    uint32_t bestGeneration = 0;
    for (uint8_t i = 0; i < EEPROM_PAGE_POOL; ++i) {
        if (readHeader(i, hdr)) {
            if (!found || hdr.generation > bestGeneration) {
                found = true;
                bestGeneration = hdr.generation;
                activePage = i;
            }
        }
    }

    if (!found) {
        activePage = 0;
        activeGeneration = 1;
        eraseLogicalPage(activePage);
        writeHeader(activePage, activeGeneration);
    }
    else {
        activeGeneration = bestGeneration;
    }

    initialized = true;
}

inline bool EEPROMEmu::readHeader(uint8_t pageIdx, PageHeader& out) const {
    const PageHeader* hdr = reinterpret_cast<const PageHeader*>(pageBase(pageIdx));
    std::memcpy(&out, hdr, sizeof(PageHeader));
    if (out.magic != kEepromPageMagic) return false;
    if (out.generation != (~out.generationInverse)) return false;
    return true;
}

inline void EEPROMEmu::writeHeader(uint8_t pageIdx, uint32_t generation) {
    PageHeader hdr{ kEepromPageMagic, generation, ~generation, 0xFFFFFFFFu };
    programBytes(pageBase(pageIdx), reinterpret_cast<const uint8_t*>(&hdr), sizeof(PageHeader));
}
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

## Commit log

2026-01-19 Add reset button recommendation for development
    Added recommendation for using a reset button during development.
2026-01-26 uploaded latest CAD
2026-01-27 3mf files Prusa Core One
    [IVEE2_Model_V4-Box_wCutouts_higher+0.5.3mf, IVEE2_Model_V5-frame_display.3mf, IVEE2_Model_V7-Keyboardmatrix.3mf]
2026-02-11 Fix typo in hardware section of README
    Corrected a typo in the README regarding wiring mistakes.
2026-02-11 Update 3D printing recommendations in README
    Corrected minor grammatical issues and clarified printing recommendations.
